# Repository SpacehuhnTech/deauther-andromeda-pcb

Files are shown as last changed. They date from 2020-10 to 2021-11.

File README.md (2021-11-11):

# Deauther Andromeda PCB
----------
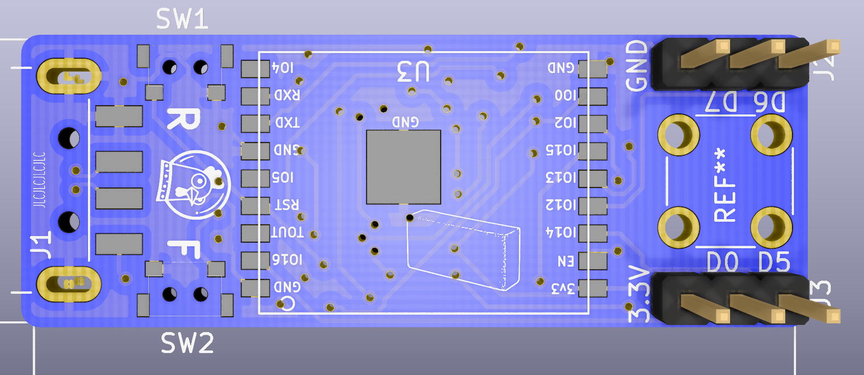
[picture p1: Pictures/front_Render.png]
<a href="https://spacehuhn.store/product/deauther-andromeda/"><br/>
Click here to purchase one from the shop</a>

PCB files for the Deauther andromeda.

Format is KiCad project.
KiCad version 5.1.4 is used during developmen prosess.

### Description
A small but powerfull board. this board is made to make full use of the wifi deauther. The serial connection is to be used for a powerfull and precise control of the deauther software.
This paired with the SMA connector, gives you the freedom to go as small and covert as you want. but you can also go big and bold. Tis power at your finger tips, just by a small and simpel extra.

A USB-powered WiFi pentesting tool based on the ESP8266.
Optimized for the [ESP8266 Deauther V3](https://github.com/SpacehuhnTech/esp8266_deauther/tree/v3) and [Huhnitor](https://github.com/spacehuhntech/huhnitor).  

Hardware features include:  
* SMA antenna connector
* USB-A plug
* ESP8266 WROOM 4MB Module
* FTDI serial chip

[Watch our video about the making-of:](https://www.youtube.com/watch?v=-opemq-5bIY)  
YouTube video link thumbnail (https://www.youtube.com/watch?v=-opemq-5bIY)

## Format

Made with [KiCad](https://kicad.org/) version 5.1.4

## Firmware

[ESP8266 Deauther](https://github.com/SpacehuhnTech/esp8266_deauther)

## License

This hardware design is published under CERN Open Hardware Licence Version 2 - Permissive, see the [license file](LICENSE) for details.

Designed by [Gerjon Eilander](https://github.com/13r1ckz) for Spacehuhn Technologies.

[Spacehuhn Technologies](https://spacehuhn.tech) invests time and resources providing this open source design, please consider supporting us by purchasing from [our store](https://spacehuhn.store).

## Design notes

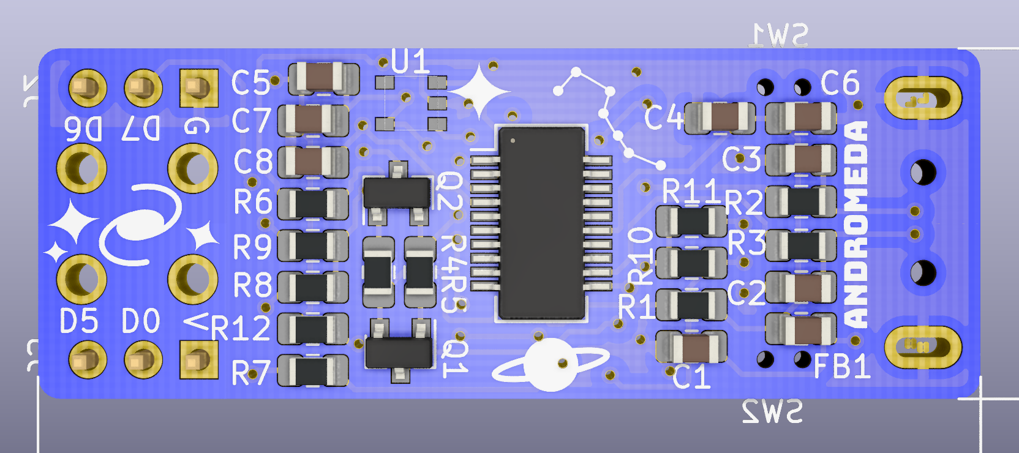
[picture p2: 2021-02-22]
Pictures/back_Render.png

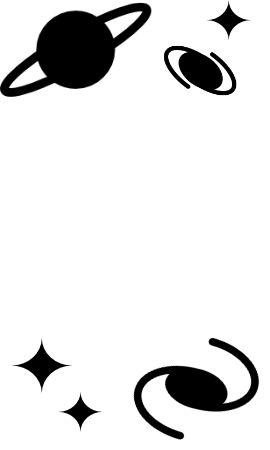
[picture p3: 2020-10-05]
Art/front.png

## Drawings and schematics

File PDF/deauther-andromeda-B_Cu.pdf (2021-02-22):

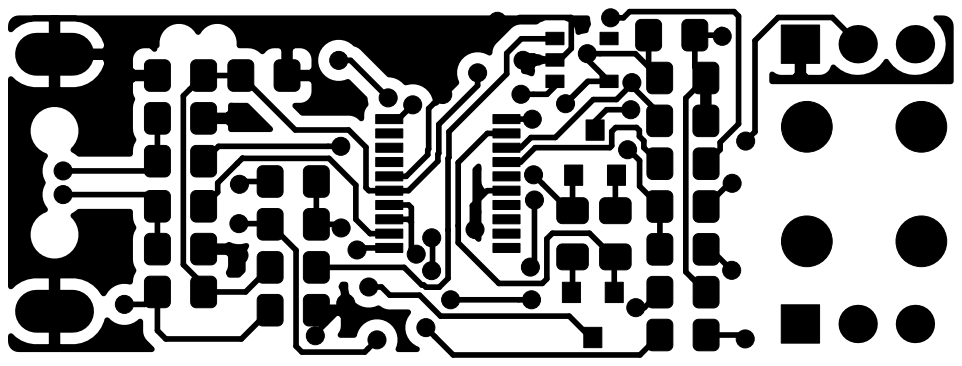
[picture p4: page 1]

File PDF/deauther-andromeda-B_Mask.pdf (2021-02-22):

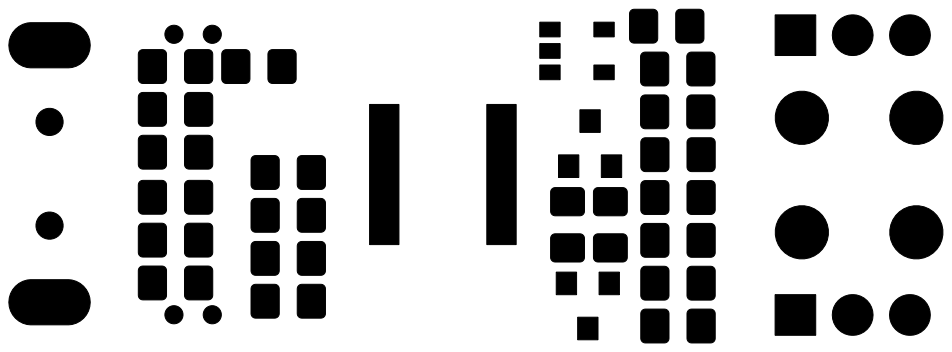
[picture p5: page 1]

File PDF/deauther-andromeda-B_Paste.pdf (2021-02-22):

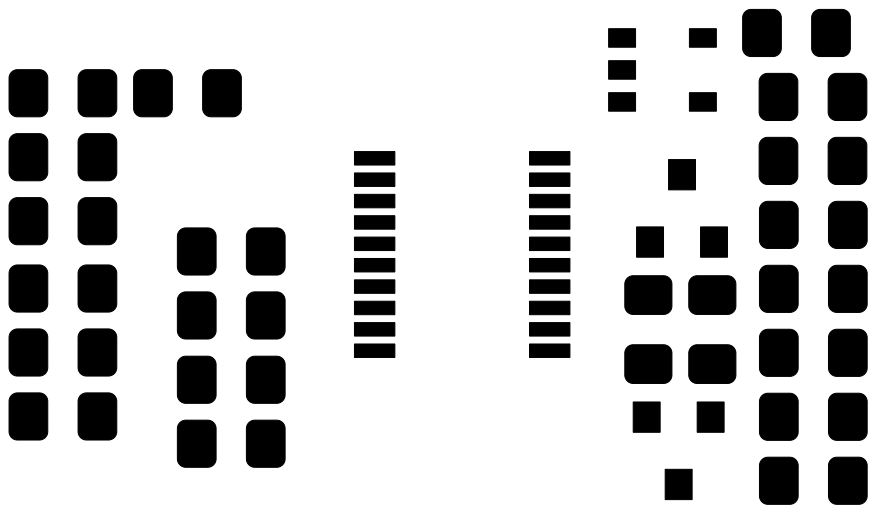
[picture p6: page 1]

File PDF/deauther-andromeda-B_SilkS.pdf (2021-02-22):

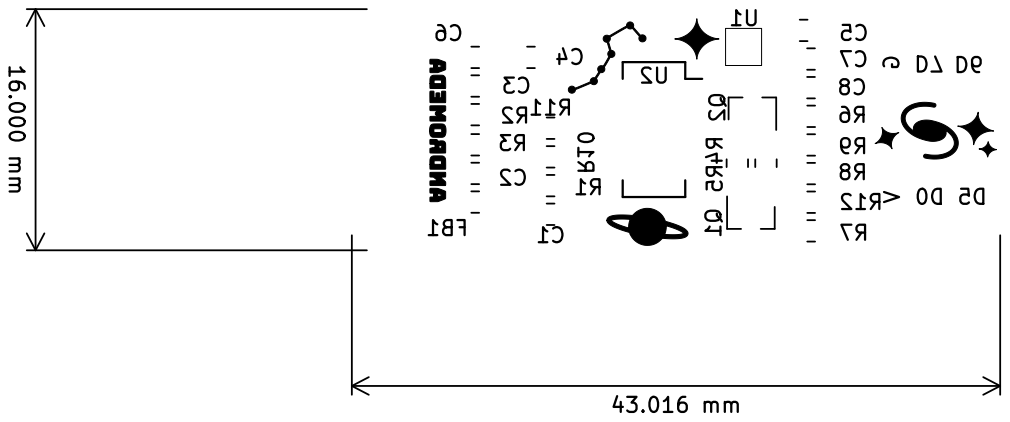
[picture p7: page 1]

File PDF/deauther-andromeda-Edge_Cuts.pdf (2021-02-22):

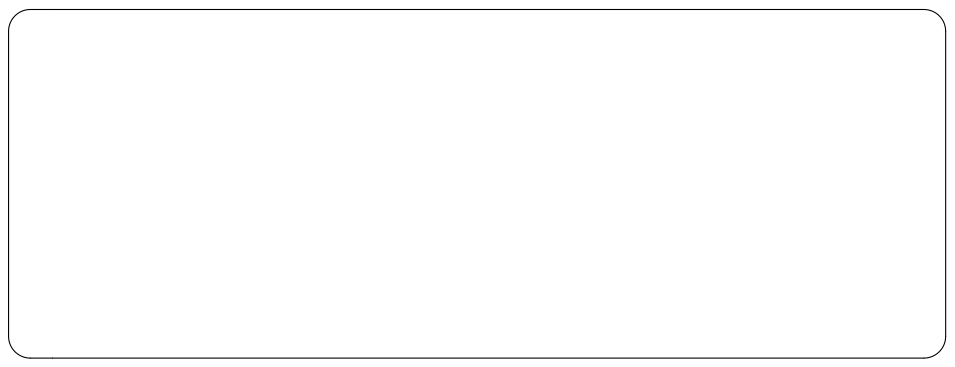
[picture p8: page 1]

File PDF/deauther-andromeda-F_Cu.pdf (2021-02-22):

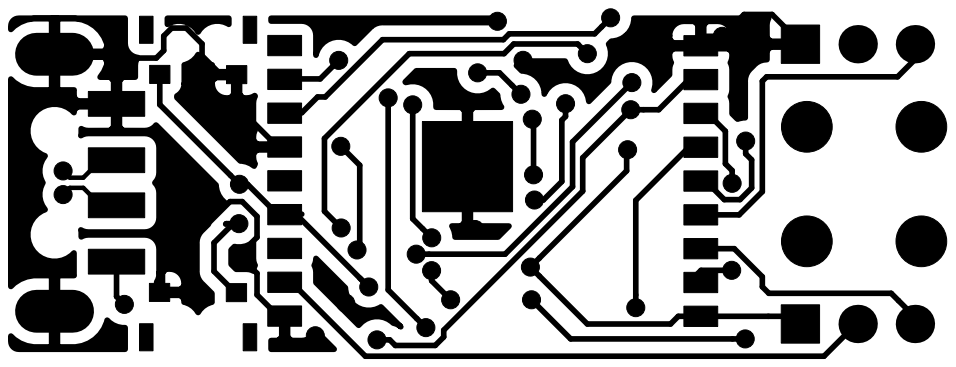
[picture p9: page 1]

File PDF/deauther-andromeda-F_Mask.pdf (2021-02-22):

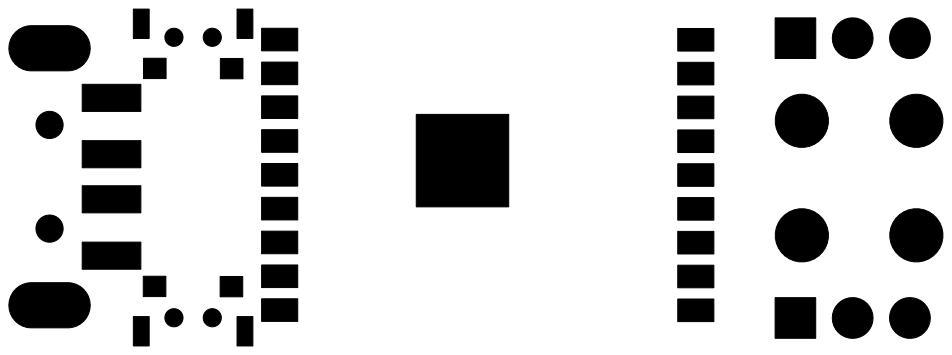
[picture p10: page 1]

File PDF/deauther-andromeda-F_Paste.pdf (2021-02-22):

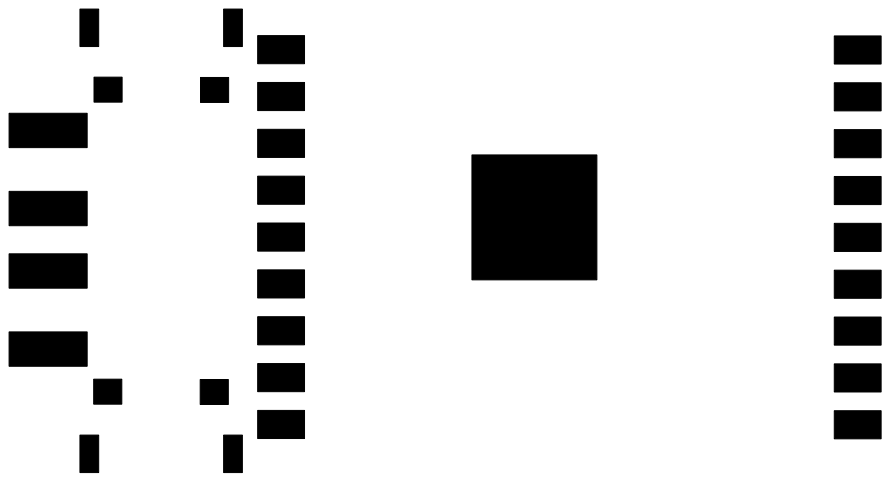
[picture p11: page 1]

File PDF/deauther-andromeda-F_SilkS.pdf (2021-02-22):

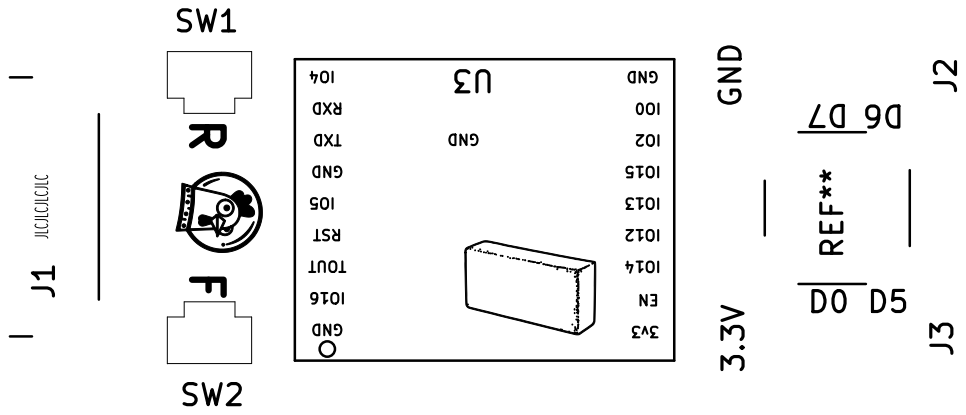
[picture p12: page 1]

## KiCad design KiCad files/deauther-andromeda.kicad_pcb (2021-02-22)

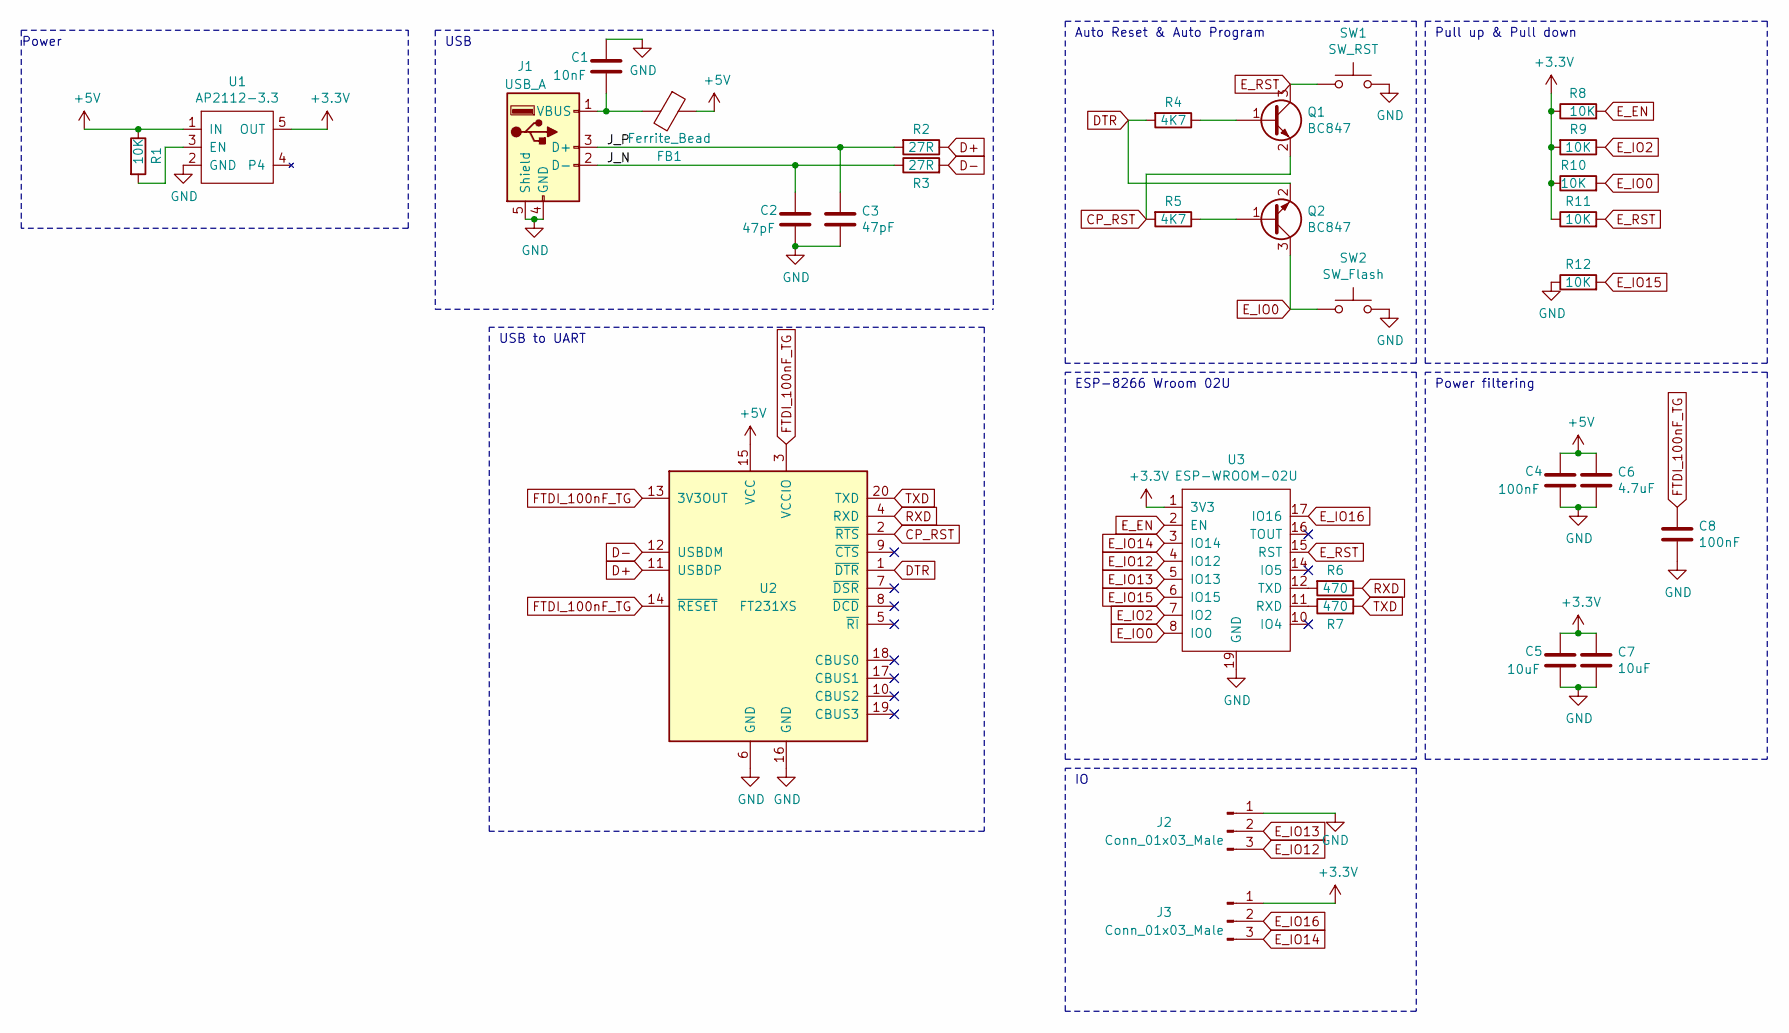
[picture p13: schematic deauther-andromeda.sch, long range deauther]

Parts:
C1: 10nF; C_0805_2012Metric_Pad1.15x1.40mm_HandSolder
C2, C3: 47pF; C_0805_2012Metric_Pad1.15x1.40mm_HandSolder
C4, C8: 100nF; C_0805_2012Metric_Pad1.15x1.40mm_HandSolder
C5, C7: 10uF; C_0805_2012Metric_Pad1.15x1.40mm_HandSolder
C6: 4.7uF; C_0805_2012Metric_Pad1.15x1.40mm_HandSolder
FB1: Ferrite_Bead; C_0805_2012Metric_Pad1.15x1.40mm_HandSolder
J1: USB_A; USB_A_CNCTech_1001-011-01101_Horizontal
J2, J3: Conn_01x03_Male; PinHeader_1x03_P2.54mm_Vertical
Q1, Q2: BC847; SOT-23
R1, R8, R9, R10, R11, R12: 10K; R_0805_2012Metric_Pad1.15x1.40mm_HandSolder
R2, R3: 27R; R_0805_2012Metric_Pad1.15x1.40mm_HandSolder
R4, R5: 4K7; R_0805_2012Metric_Pad1.15x1.40mm_HandSolder
R6, R7: 470; R_0805_2012Metric_Pad1.15x1.40mm_HandSolder
SW1: SW_RST; HYP_1TS003B-1600-3500A-CT
SW2: SW_Flash; HYP_1TS003B-1600-3500A-CT
U1: AP2112-3.3; AP2112_REGULATOR
U2: FT231XS; SSOP-20_3.9x8.7mm_P0.635mm
U3: ESP-WROOM-02U

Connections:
+3V3: C5.1, C7.1, J3.1, R8.1, R9.2, R10.1, R11.1, U1.5 (OUT), U3.1 (3V3)
+5V: C4.1, C6.1, FB1.1, R1.1, U1.1 (IN), U2.15 (VCC)
/J_N: C2.2, J1.2 (D-), R3.1
/J_P: C3.1, J1.3 (D+), R2.2
CP_RST: Q1.2 (E), R5.2, U2.2 (~RTS)
D+: R2.1, U2.11 (USBDP)
D-: R3.2, U2.12 (USBDM)
DTR: Q2.2 (E), R4.2, U2.1 (~DTR)
E_EN: R8.2, U3.2 (EN)
E_IO0: Q2.3 (C), R10.2, SW2.1, U3.8 (IO0)
E_IO2: R9.1, U3.7 (IO2)
E_IO12: J2.3, U3.4 (IO12)
E_IO13: J2.2, U3.5 (IO13)
E_IO14: J3.3, U3.3 (IO14)
E_IO15: R12.2, U3.6 (IO15)
E_IO16: J3.2, U3.17 (IO16)
E_RST: Q1.3 (C), R11.2, SW1.1, U3.15 (RST)
FTDI_100nF_TG: C8.1, U2.3 (VCCIO), U2.13 (3V3OUT), U2.14 (~RESET)
GND: C1.2, C2.1, C3.2, C4.2, C5.2, C6.2, C7.2, C8.2, J1.4 (GND), J1.5 (Shield), J2.1, R12.1, SW1.2, SW2.2, U1.2 (GND), U2.6 (GND), U2.16 (GND), U3.9 (GND), U3.13 (GND), U3.18 (GND), U3.19 (GND)
unnamed: C1.1, FB1.2, J1.1 (VBUS)
unnamed: Q1.1 (B), R4.1
unnamed: Q2.1 (B), R5.1
unnamed: R1.2, U1.3 (EN)
unnamed: R6.2, U3.12 (TXD)
unnamed: R7.1, U3.11 (RXD)
RXD: R6.1, U2.4 (RXD)
TXD: R7.2, U2.20 (TXD)

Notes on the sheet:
Power
USB
USB to UART
Auto Reset & Auto Program
Pull up & Pull down
ESP-8266 Wroom 02U
Power filtering

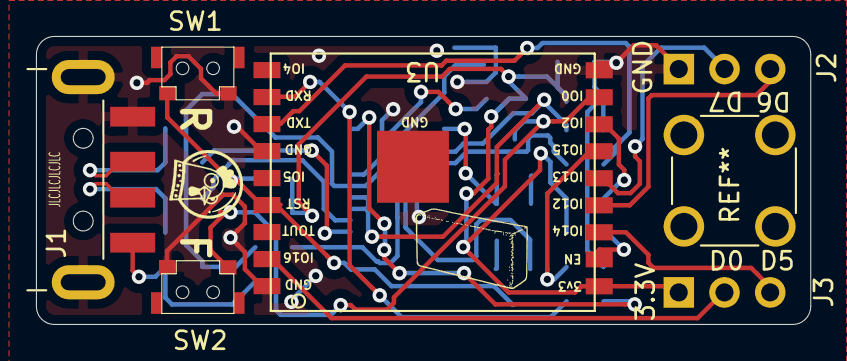
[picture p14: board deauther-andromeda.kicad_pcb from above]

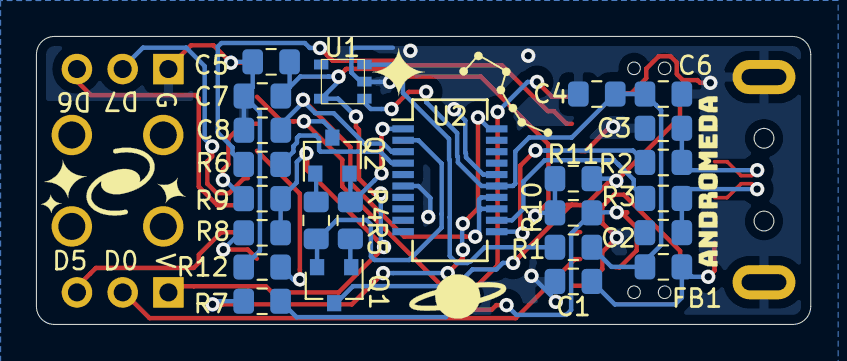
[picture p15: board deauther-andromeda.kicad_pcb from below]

Board: 2 copper layers, 43.0 x 16.0 mm, 31 parts (25 on the bottom side), 27 nets.

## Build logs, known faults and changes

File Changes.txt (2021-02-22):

V1:
initial version limited edition version.

V1.1 Andromeda Hackerinterchange
new usb serial chip.
change of buttons.
smd usb.
esp8266 footprint change.
new regulator.
change via locations.
Add art

V1.2 Andromeda 
Io pin acces.

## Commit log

2020-10-02 next update with some update on pcb
    these updates are for use and for production.
    Changes are quickly listed in the changes.txt
    [Long range deauther-B_Cu.gbr, Long range deauther-B_Mask.gbr, Long range deauther-B_Paste.gbr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]
2020-10-04 Andromeda idiot fix (#2)
    * fixed idiote trace mistake
    * updated the gerbers .zip
    [Long range deauther-B_Cu.gbr, Long range deauther-B_Mask.gbr, Long range deauther-B_Paste.gbr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]
2020-10-04 Add artwork on to pcb
    [Long range deauther-B_Cu.gbr, Long range deauther-B_Mask.gbr, Long range deauther-B_Paste.gbr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]
2020-10-05 Will need to verify if these are right and if kicad has some issue with github or something. when opening the file after a day or after a git action some copper traces apear to change.
    [Long range deauther-B_Cu.gbr, Long range deauther-B_Mask.gbr, Long range deauther-B_Paste.gbr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]
2020-10-19 inbetween push to pull on linux
    [Long range deauther-B_Cu.gbr, Long range deauther-B_Mask.gbr, Long range deauther-B_Paste.gbr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]
2020-11-01 Def board version
    [Long range deauther-B_Cu.gbr, Long range deauther-B_Mask.gbr, Long range deauther-B_Paste.gbr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]
2021-03-01 fabrication commits 2 add fidus to pannel
    [pannel.kicad_pcb, pannel_clean.kicad_pcb]
2021-11-10 Update README.md
    https://forum.kicad.info/t/warning-avoid-all-links-to-kicad-pcb-org-use-kicad-org/31521
